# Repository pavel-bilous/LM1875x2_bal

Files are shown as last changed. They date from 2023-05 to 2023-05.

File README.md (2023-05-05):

# Two paralleled LM1875 ICs schematics and PCB design

Benefits of using two chips in parallel include: increase of the output drive capability of an amplifier, reduced voltage noise (better SNR), and reduced output offset error.

Resources used to design this amp:

Official datasheet - [https://www.ti.com/lit/gpn/lm1875](https://www.ti.com/lit/gpn/lm1875)

## PCB rendered in 3d:
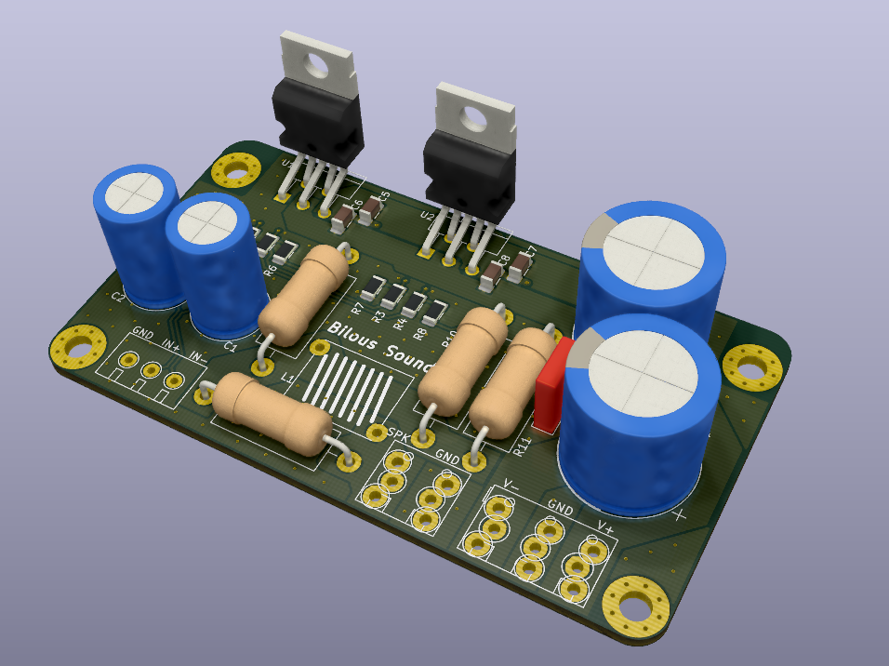
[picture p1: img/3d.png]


## Schematics:

Two paralleled LM1875 are used to double the current drive and to increase the power output. Safe voltage to power the amplifier is 28V.
Gain is set to a minimum recommended in the datasheet of 10 V/V.

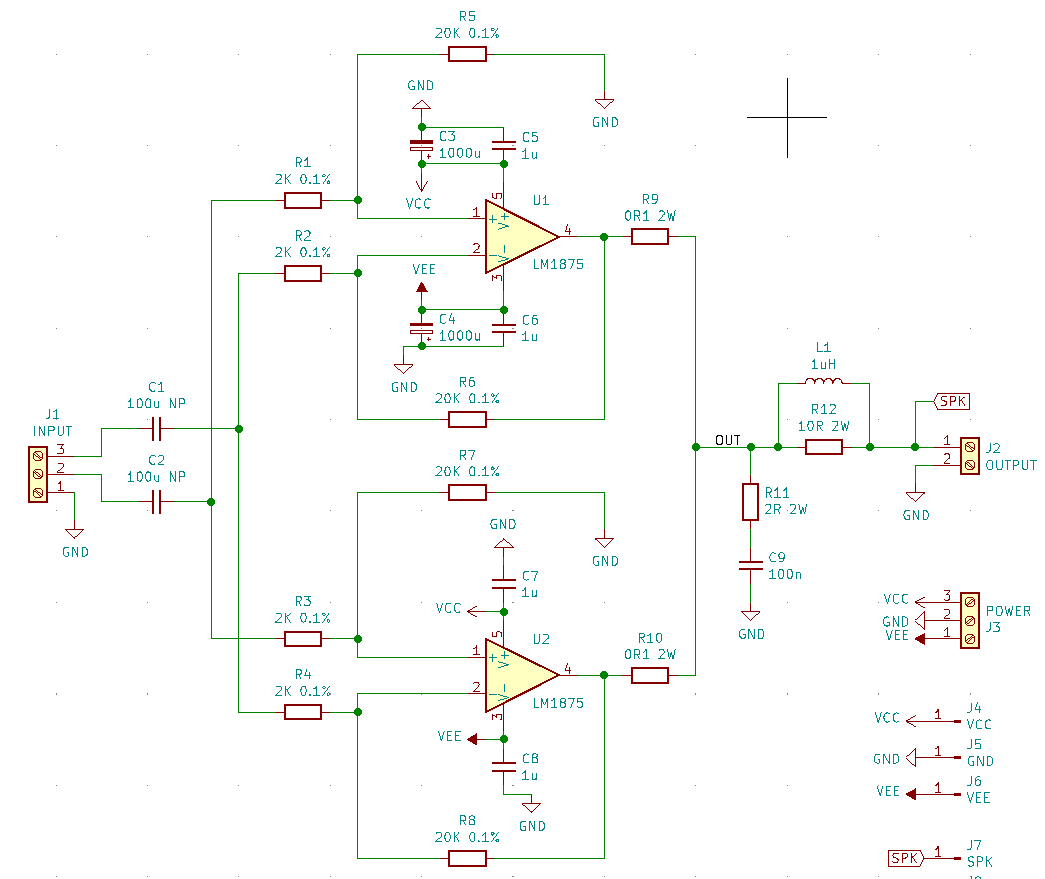
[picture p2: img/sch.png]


## PCB layout:

Bottom layer is GND. Top layer is signal + power and GND poured in between. Stiching vias are then applied to connect bottom and top GND planes to ensure those are as close to 0 as possible.

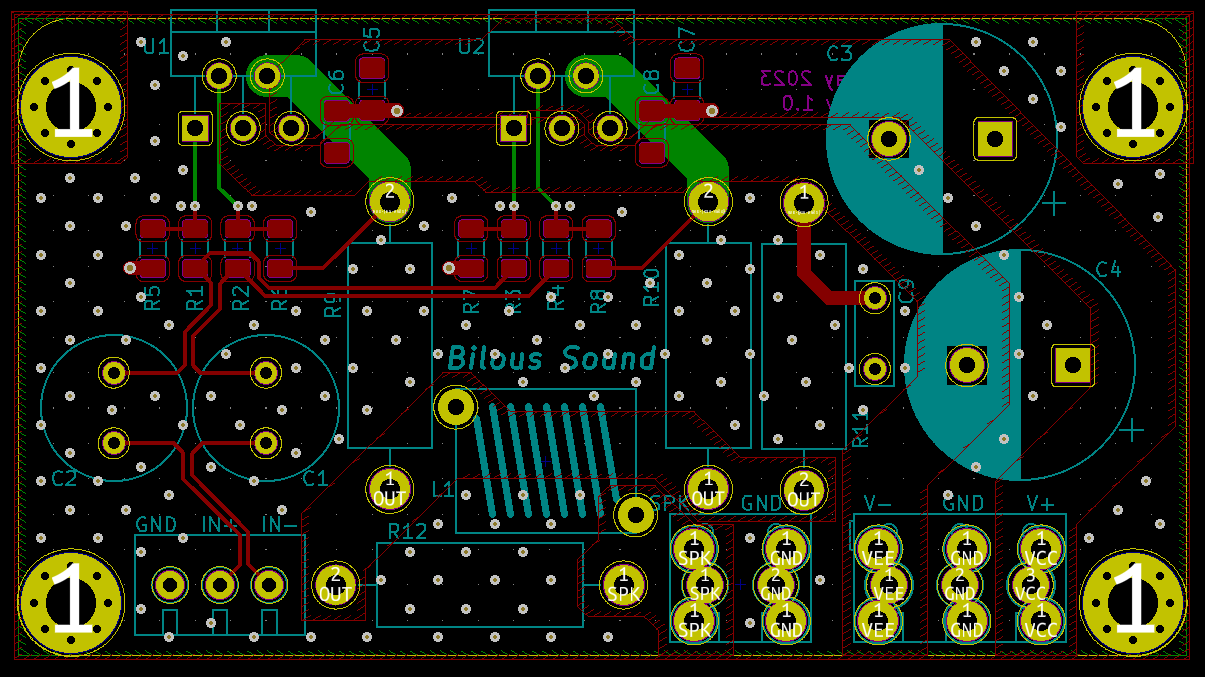
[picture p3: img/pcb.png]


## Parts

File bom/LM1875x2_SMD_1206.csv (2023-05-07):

Id | Designator | Package | Quantity | Designation | Supplier and ref
1 | C9 | C_Rect_L7.2mm_W2.5mm_P5.00mm_FKS2_FKP2_MKS2_MKP2 | 1 | 100n
2 | J8,J5 | Terminal_.25_PCB_TAB_TE_Connectivity_P5.08mm_ | 2 | GND
3 | J7 | Terminal_.25_PCB_TAB_TE_Connectivity_P5.08mm_ | 1 | SPK
4 | J6 | Terminal_.25_PCB_TAB_TE_Connectivity_P5.08mm_ | 1 | VEE
5 | J4 | Terminal_.25_PCB_TAB_TE_Connectivity_P5.08mm_ | 1 | VCC
6 | H4,H3,H2,H1 | MountingHole_3.5mm_Pad_Via | 4 | MountingHole
7 | L1 | Inductor_DIY_flipped | 1 | 1uH
8 | C8,C7,C6,C5 | C_1206_3216Metric_Pad1.42x1.75mm_HandSolder | 4 | 1u
9 | U2,U1 | TO-220-5_P3.4x3.7mm_StaggerOdd_Lead3.8mm_Vertical | 2 | LM1875
10 | R12 | R_Axial_DIN0614_L14.3mm_D5.7mm_P20.32mm_Horizontal | 1 | 10R 2W
11 | R11 | R_Axial_DIN0614_L14.3mm_D5.7mm_P20.32mm_Horizontal | 1 | 2R 2W
12 | R10,R9 | R_Axial_DIN0614_L14.3mm_D5.7mm_P20.32mm_Horizontal | 2 | 0R1 2W
13 | R8,R7,R6,R5 | R_1206_3216Metric | 4 | 20K 0.1%
14 | R4,R3,R2,R1 | R_1206_3216Metric | 4 | 2K 0.1%
15 | J3 | TerminalBlock_CUI_01x03_P5.00mm | 1 | POWER
16 | J2 | TerminalBlock_CUI_01x02_P5.00mm | 1 | OUTPUT
17 | J1 | TerminalBlock_ Amphenol_01_03_P3.50mm | 1 | INPUT
18 | C4,C3 | CP_Radial_D16.0mm_P7.50mm | 2 | 1000u
19 | C2,C1 | C_Radial_D10.0mm_H16.0mm_P5.00mm | 2 | 100u NP

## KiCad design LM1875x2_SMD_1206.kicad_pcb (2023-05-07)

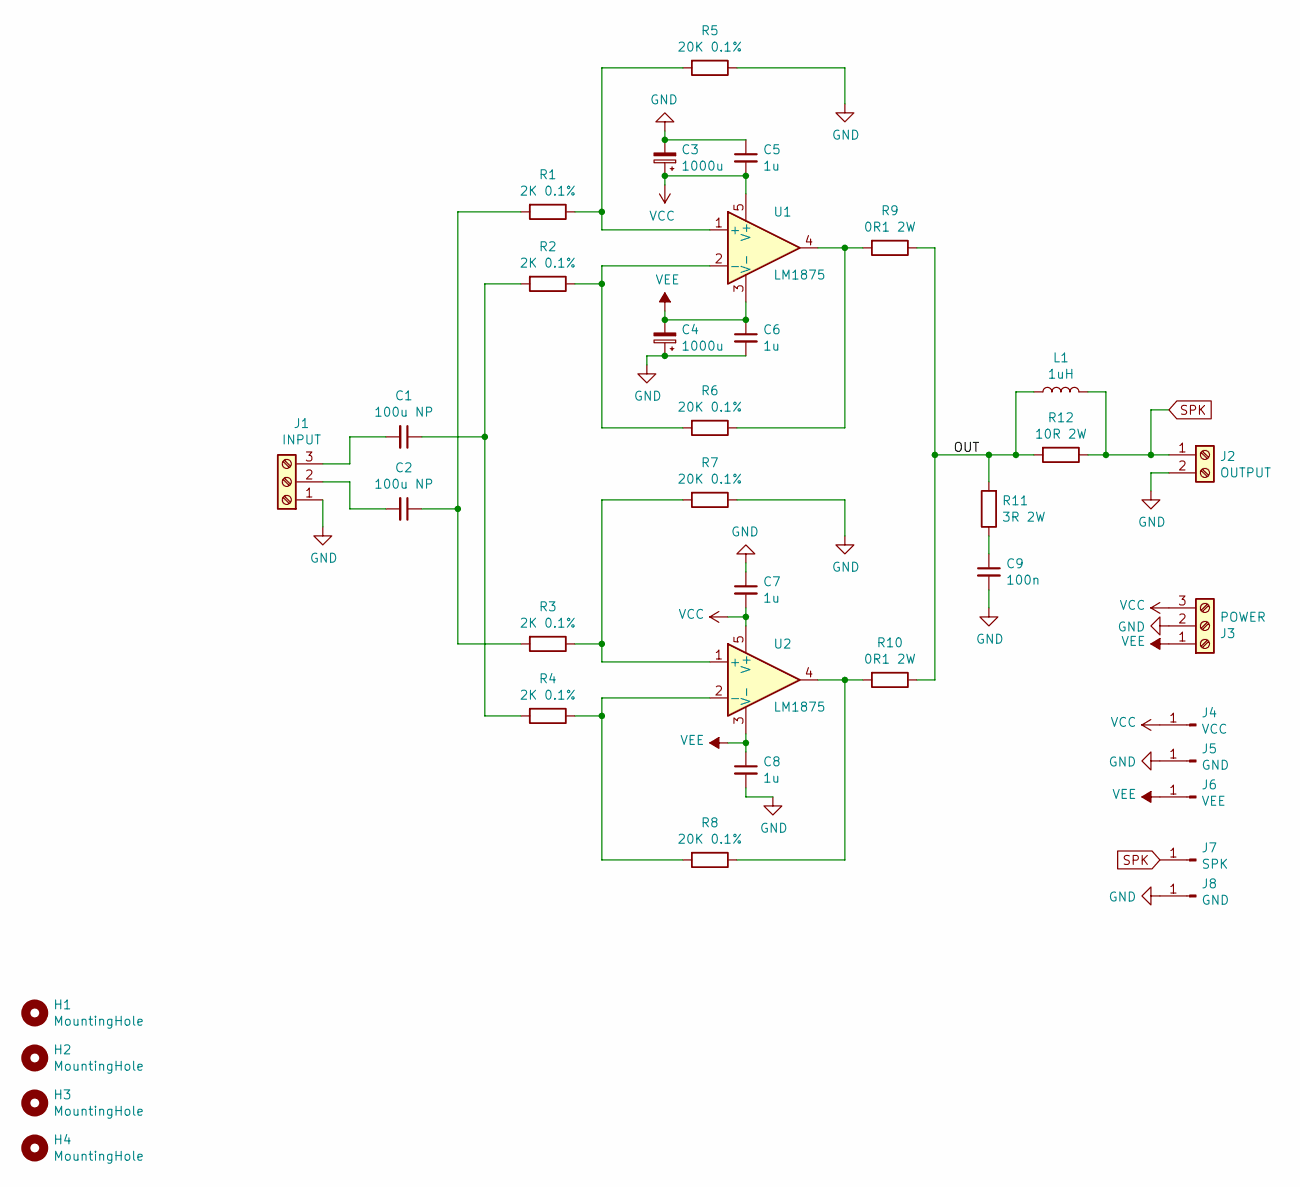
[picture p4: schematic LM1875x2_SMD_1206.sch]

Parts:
C1, C2: 100u NP; C_Radial_D10.0mm_H16.0mm_P5.00mm
C3, C4: 1000u; CP_Radial_D16.0mm_P7.50mm
C5, C6, C7, C8: 1u; C_1206_3216Metric_Pad1.42x1.75mm_HandSolder
C9: 100n; C_Rect_L7.2mm_W2.5mm_P5.00mm_FKS2_FKP2_MKS2_MKP2
H1, H2, H3, H4: MountingHole; MountingHole_3.5mm_Pad_Via
J1: INPUT; TerminalBlock_ Amphenol_01_03_P3.50mm
J2: OUTPUT; TerminalBlock_CUI_01x02_P5.00mm
J3: POWER; TerminalBlock_CUI_01x03_P5.00mm
J4: VCC; Terminal_.25_PCB_TAB_TE_Connectivity_P5.08mm_
J5, J8: GND; Terminal_.25_PCB_TAB_TE_Connectivity_P5.08mm_
J6: VEE; Terminal_.25_PCB_TAB_TE_Connectivity_P5.08mm_
J7: SPK; Terminal_.25_PCB_TAB_TE_Connectivity_P5.08mm_
L1: 1uH; Inductor_DIY_flipped
R1, R2, R3, R4: 2K 0.1%; R_1206_3216Metric
R5, R6, R7, R8: 20K 0.1%; R_1206_3216Metric
R9, R10: 0R1 2W; R_Axial_DIN0614_L14.3mm_D5.7mm_P20.32mm_Horizontal
R11: 3R 2W; R_Axial_DIN0614_L14.3mm_D5.7mm_P20.32mm_Horizontal
R12: 10R 2W; R_Axial_DIN0614_L14.3mm_D5.7mm_P20.32mm_Horizontal
U1, U2: LM1875; TO-220-5_P3.4x3.7mm_StaggerOdd_Lead3.8mm_Vertical

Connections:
/OUT: L1.1, R9.1, R10.1, R11.2, R12.2
GND: C3.2, C4.1, C5.1, C6.2, C7.1, C8.2, C9.2, J1.1, J2.2, J3.2, J5.1, J8.1, R5.1, R7.1
unnamed: C1.1, R2.2, R4.2
unnamed: C1.2, J1.3
unnamed: C2.1, R1.2, R3.2
unnamed: C2.2, J1.2
unnamed: C9.1, R11.1
unnamed: R1.1, R5.2, U1.1 (+)
unnamed: R2.1, R6.2, U1.2 (-)
unnamed: R3.1, R7.2, U2.1 (+)
unnamed: R4.1, R8.2, U2.2 (-)
unnamed: R6.1, R9.2, U1.4
unnamed: R8.1, R10.2, U2.4
SPK: J2.1, J7.1, L1.2, R12.1
VCC: C3.1, C5.2, C7.2, J3.3, J4.1, U1.5 (V+), U2.5 (V+)
VEE: C4.2, C6.1, C8.1, J3.1, J6.1, U1.3 (V-), U2.3 (V-)

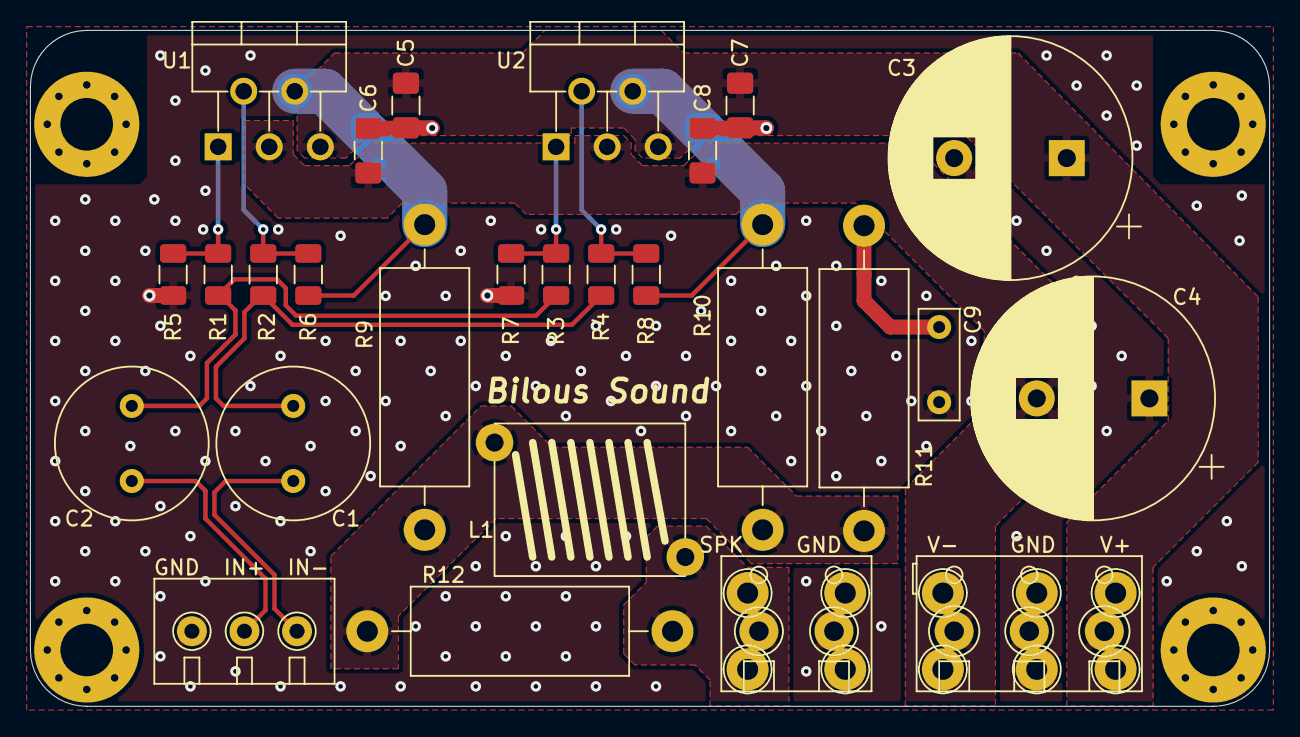
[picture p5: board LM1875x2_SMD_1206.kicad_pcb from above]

Board: 2 copper layers, 82.5 x 45.0 mm, 36 parts (0 on the bottom side), 16 nets.

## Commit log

2023-05-04 rearranged elements
    [LM1875x2_SMD_1206.kicad_pcb, LM1875x2_SMD_1206.sch]
2023-05-05 finished layout
    [LM1875x2_SMD_1206.kicad_pcb, LM1875x2_SMD_1206.sch]
2023-05-05 added production files
    [LM1875x2_SMD_1206-B_Cu.gbr, LM1875x2_SMD_1206-B_Mask.gbr, LM1875x2_SMD_1206-B_Paste.gbr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]
2023-05-06 updated film cap footprint
    [LM1875x2_SMD_1206-B_Cu.gbr, LM1875x2_SMD_1206-B_Mask.gbr, LM1875x2_SMD_1206-B_Paste.gbr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]
2023-05-07 minor fixes
    [LM1875x2_SMD_1206-B_Cu.gbr, LM1875x2_SMD_1206-B_Mask.gbr, LM1875x2_SMD_1206-B_Paste.gbr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]
